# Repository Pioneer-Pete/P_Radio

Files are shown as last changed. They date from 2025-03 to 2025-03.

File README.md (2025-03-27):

## Introduciton

P_Radio was created as a homage to the iconic radios seen in the Portal video game series, to be distributed around UW-Platteville on April 1st, 2025.
The project's goal was to create an accurate representation of the Portal radios, both in appearance and sound, while retaining a sub-dollar cost per unit to enable a large number of units to be created and distributed.
Excluding the 3D printing costs, each unit meets the original goal, coming in at exactly $1. Filament costs ended up being approximately $0.40 per unit.

## Project Information

 3D Models: The base and shell were modeled in Fusion 360. STEP, STL, and F3D files are included.
 
 PCB Design: A custom PCB was designed using KiCAD, and four expansion ports were included for any future tinkerers out there.
 
 Code: The radio is powered by an STM8S003F3, a cost-effective 8-bit microcontroller. This necessitated using STM's STVD and STVP to program the boards. If remaking the project, I would look into using the STM Arduino library instead.

 Assembly: Everything snaps together without any hardware; the hole at the top of the shell accepts a ~4-inch length of standard 1.75mm filament to act as the "antenna". The batteries require a small strip of aluminum foil to complete the circuit at the end opposite the PCB. The calculated battery lifespan is 1-2 months, but it has yet to be tested.

## Fine Print

This is a non-commercial, personal project created for an April Fools' joke at the UW-Platteville campus. All copyrightable content (such as the Aperture Science logo) is the property of its respective owners and is used here for parody purposes only.

Feel free to use and modify the project as you like for fun, but please do not distribute any copyrighted content (logos, names) for commercial purposes.

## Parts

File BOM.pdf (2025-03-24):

Name | Part# | Cost/100 | Cost/150 | Cost/200 | Cost/300 | Cost/500
PCB | N/A | $ | 0.1834 | $ | 0.1623 | $ | 0.1591 | $ | 0.1559 | $ | 0.1521
MCU | STM8S003F3P6TR | $ 0.2305 | $ | 0.2004 | $ | 0.2004 | $ | 0.2004 | $ | 0.1735
VREG | MD3156E33QA3 | $ | 0.1005 | $ | 0.0871 | $ | 0.0871 | $ | 0.0871 | $ | 0.0770
Buzzer | SFN-1207PA6.5 | $ 0.0563 | $ 0.0563 | $ 0.0563 | $ | 0.0489 | $ | 0.0489
L | MGFL2012F2R2MT-LF | $ 0.0186 | $ 0.0186 | $ 0.0143 | $ | 0.0143 | $ | 0.0143
C1, C2 | CL10A105KO8NNNC | $ 0.0058 | $ 0.0058 | $ 0.0058 | $ | 0.0058 | $ | 0.0044
C5 | CL10A106MQ8NNNC | $ 0.0041 | $ 0.0041 | $ 0.0041 | $ | 0.0041 | $ | 0.0032
R1, R2 | TBD | $ 0.0020 | $ 0.0020 | $ 0.0020 | $ | 0.0020 | $ | 0.0020
AA Battery | N/A | $ 0.4028 | $ 0.4332 | $ 0.4483 | $ | 0.4635 | $ | 0.4756
3D Print | N/A | $ 0.4000 | $ 0.4000 | $ 0.4000 | $ | 0.4000 | $ | 0.4000
Per Unit | $ | 1.40 $ | 1.37 $ | 1.38 $ | 1.38 $ | 1.35
Total | $ | 140.40 $ | 205.47 $ | 275.48 $ | 414.60 $ | 675.50

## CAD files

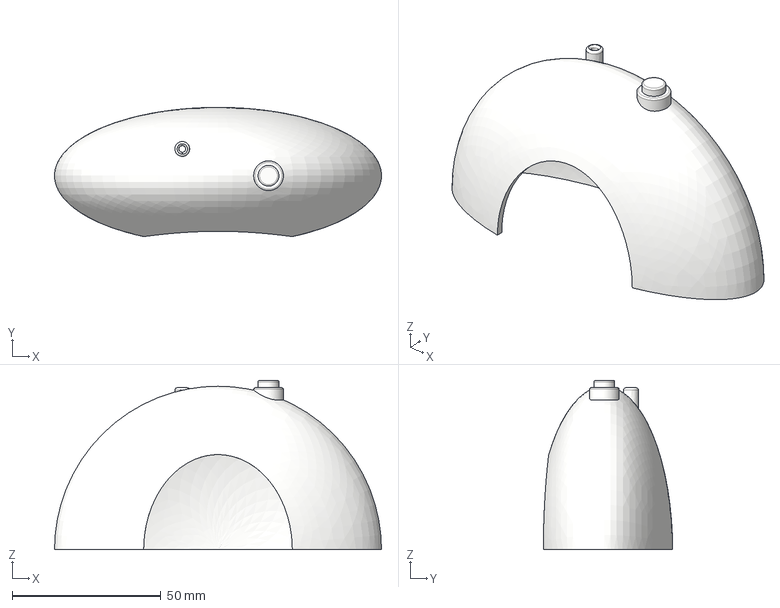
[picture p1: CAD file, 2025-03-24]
3D Models/Portal Radio Shell v8.step
110.0 x 43.5 x 57.0 mm

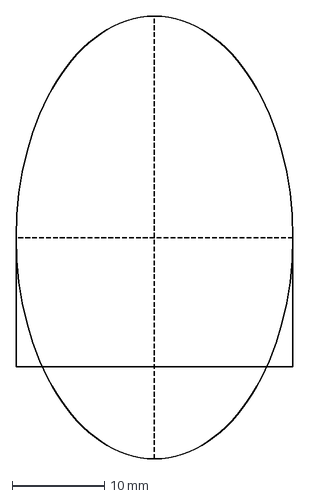
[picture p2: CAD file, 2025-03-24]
PCB/PCB Outine.dxf
30.0 x 48.0 mm

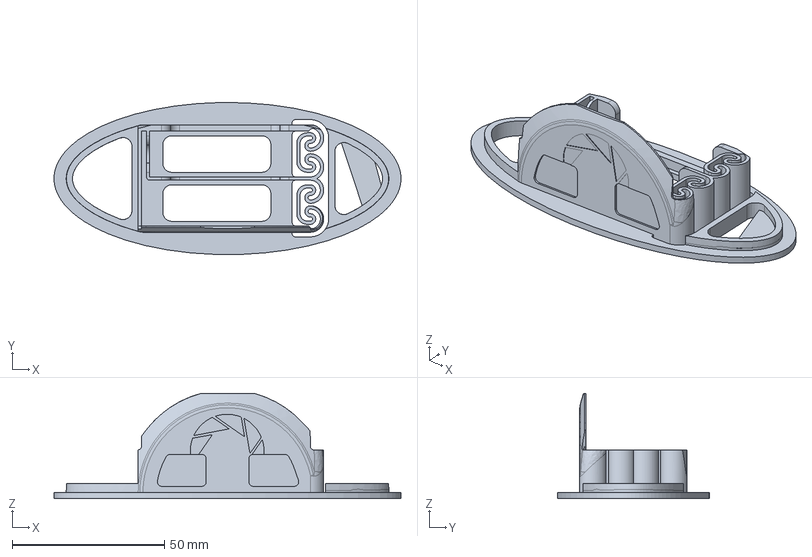
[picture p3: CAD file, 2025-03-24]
3D Models/Portal Radio Base v14.step
114.0 x 49.9 x 34.5 mm

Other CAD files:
3D Models/Portal Radio Base v14.f3d
3D Models/Portal Radio Shell v8.f3d

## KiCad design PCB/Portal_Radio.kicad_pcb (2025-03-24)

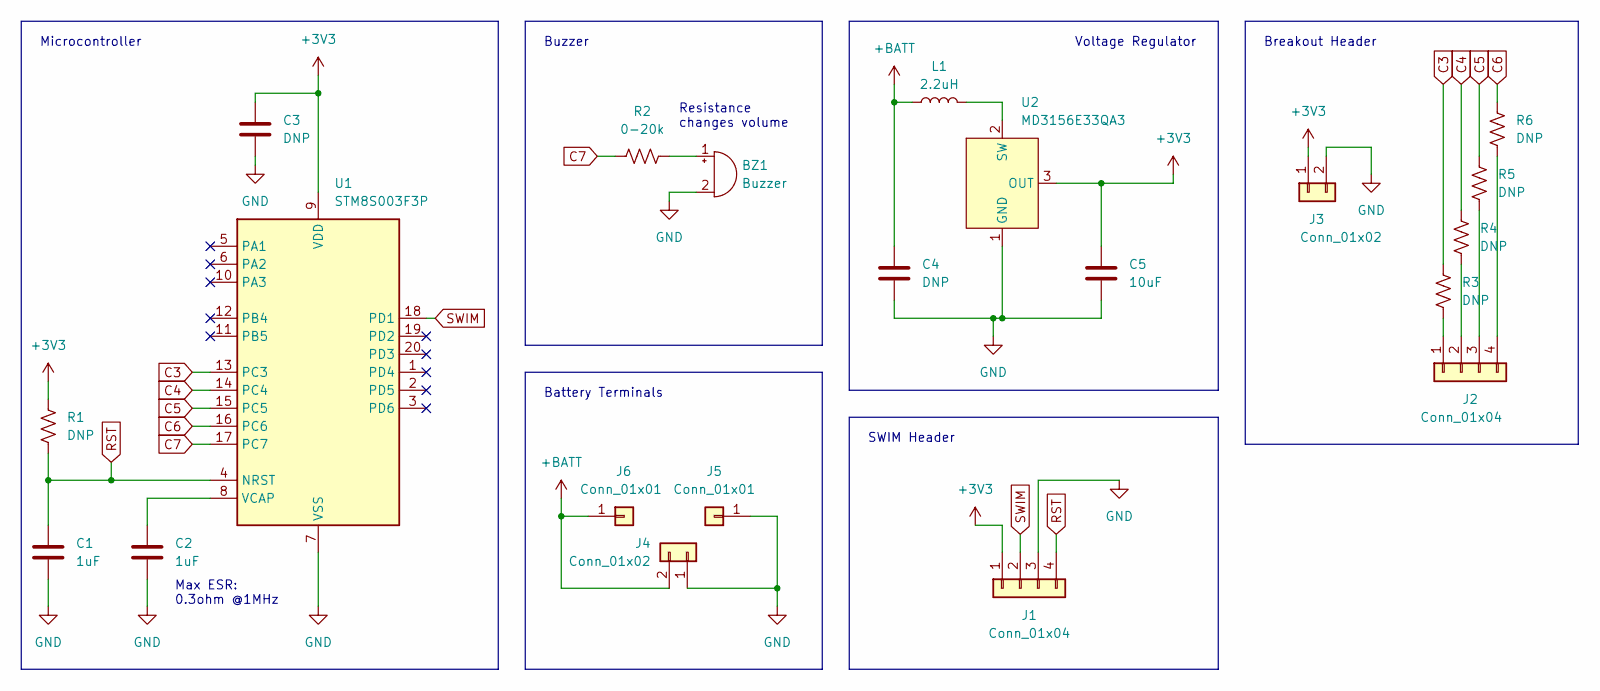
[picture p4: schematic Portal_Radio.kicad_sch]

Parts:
BZ1: Buzzer; MagneticBuzzer_ProSignal_ABT-410-RC
C1, C2: 1uF; C_0603_1608Metric
C3, C4: DNP; C_0603_1608Metric
C5: 10uF; C_0603_1608Metric
J1, J2: Conn_01x04; PinHeader_1x04_P2.54mm_Vertical
J3, J4: Conn_01x02; PinHeader_1x02_P2.54mm_Vertical
J5, J6: Conn_01x01; AA_Battery
L1: 2.2uH; L_0603_1608Metric
R1, R3, R4, R5, R6: DNP; R_0603_1608Metric
R2: 0-20k; R_0603_1608Metric
U1: STM8S003F3P; TSSOP-20_4.4x6.5mm_P0.65mm
U2: MD3156E33QA3; SOT-23-3

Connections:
+3V3: C3.1, C5.1, J1.1, J3.1, R1.1, U1.9 (VDD), U2.3 (OUT)
+BATT: C4.1, J4.2, J6.1, L1.1
C3: R3.1, U1.13 (PC3)
C4: R4.1, U1.14 (PC4)
C5: R5.1, U1.15 (PC5)
C6: R6.1, U1.16 (PC6)
C7: R2.1, U1.17 (PC7)
GND: BZ1.2 (-), C1.2, C2.2, C3.2, C4.2, C5.2, J1.3, J3.2, J4.1, J5.1, U1.7 (VSS), U2.1 (GND)
unnamed: BZ1.1 (+), R2.2
unnamed: J2.1, R3.2
unnamed: J2.2, R4.2
unnamed: J2.3, R5.2
unnamed: J2.4, R6.2
unnamed: C2.1, U1.8 (VCAP)
unnamed: L1.2, U2.2 (SW)
RST: C1.1, J1.4, R1.2, U1.4 (NRST)
SWIM: J1.2, U1.18 (PD1)

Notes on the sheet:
Resistance changes volume
Buzzer
Breakout Header
Voltage Regulator
Battery Terminals
Max ESR: 0.3ohm @1MHz
SWIM Header
Microcontroller

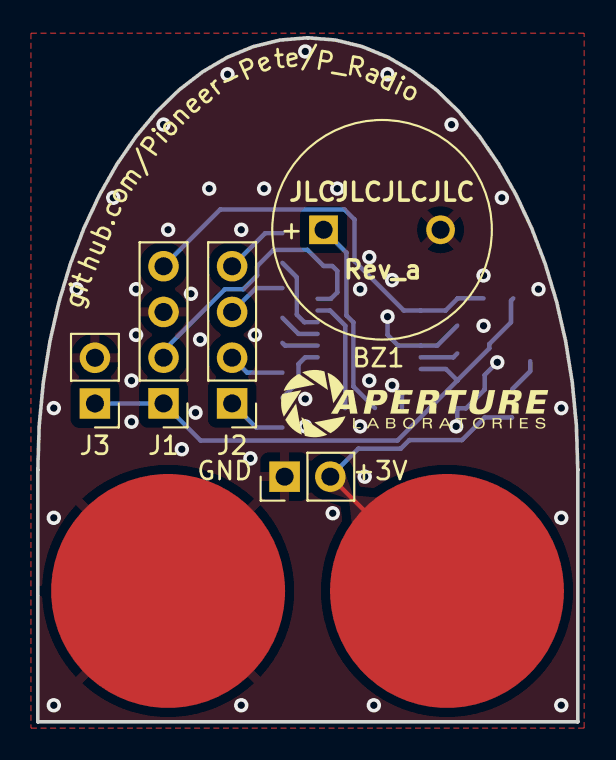
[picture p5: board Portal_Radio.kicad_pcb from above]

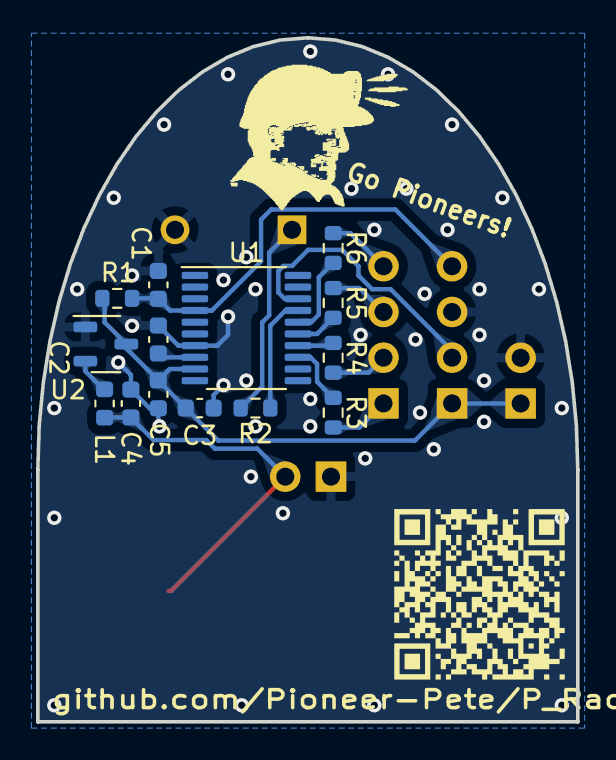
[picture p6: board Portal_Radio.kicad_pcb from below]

Board: 2 copper layers, 30.0 x 38.0 mm, 21 parts (14 on the bottom side), 17 nets.

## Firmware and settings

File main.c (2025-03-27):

#include "main.h"

#define EEPROM_STARTUP_DELAY_ADDR   ((uint32_t) FLASH_DATA_START_PHYSICAL_ADDRESS)

#define N_A6S  268  // A#6
#define N_A6   284  // A6
#define N_G6   318  // G6
#define N_F6S  337  // F#6
#define N_F6   357  // F6
#define N_E6   379  // E6
#define N_D6S  401  // D#6
#define N_D6   425  // D6
#define N_C6S  450  // C#6
#define N_C6   478  // C6
#define N_B5   506  // B5
#define N_A5S  536  // A#5
#define N_A5   568  // A5
#define N_G5S  601  // G#5
#define N_G5   637  // G5
#define N_F5S  675  // F#5
#define N_F5   716  // F5
#define N_E5   758  // E5
#define N_D5S  803  // D#5
#define N_D5   851  // D5
#define N_C5S  902  // C#5
#define N_C5   956  // C5
#define N_B4   1012 // B4
#define N_A4S  1072 // A#4
#define N_A4   1136 // A4
#define N_G4S  1204 // G#4
#define N_G4   1275 // G4
#define N_F4S  1351 // F#4
#define N_F4   1432 // F4
#define N_E4   1515 // E4
#define N_D4S  1607 // D#4
#define N_D4   1700 // D4
#define N_0    0    // Silence

// Note array 
const uint16_t notes[] = {
  N_D4,  N_D4,  N_0,   N_D4,  N_F4S, N_F4S, N_0,   N_F4S, N_G4,  N_0,   N_G4,  N_B4,  N_0,   N_B4,  N_A4,  N_0,   
  N_F4S, N_F4S, N_0,   N_F4S, N_G4,  N_G4,  N_0,   N_G4,  N_A4,  N_A4,  N_0,   N_B4,  N_G6,  N_F6S, N_A4,  N_E6,  
  N_D4,  N_D4,  N_F6S, N_D4,  N_F4S, N_F4S, N_D5,  N_F4S, N_G4,  N_0,   N_G4,  N_B4,  N_G6,  N_F6S, N_A4,  N_E6,  
  N_D4,  N_D4,  N_F6S, N_D4,  N_D6,  N_F4S, N_E6,  N_A5,  N_G4,  N_0,   N_G4,  N_B4,  N_0,   N_B4,  N_A4,  N_0,   
  N_E6,  N_D5,  N_F6S, N_G6,  N_G5,  N_E6,  N_E6,  N_0,   N_C6S, N_C5S, N_D6,  N_E6,  N_E5,  N_A5,  N_A4,  N_0,   
  N_A5,  N_A5,  N_A5,  N_D4,  N_F4S, N_F4S, N_D5,  N_F4S, N_G4,  N_0,   N_G4,  N_B4,  N_G6,  N_F6S, N_A4,  N_E6,  
  N_D4,  N_D4,  N_F6S, N_D4,  N_F4S, N_F4S, N_D5,  N_F4S, N_G4,  N_0,   N_G4,  N_B4,  N_G6,  N_F6S, N_A4,  N_E6,  
  N_D4,  N_D4,  N_F6S, N_D4,  N_D6,  N_F4S, N_E6,  N_A5,  N_G4,  N_0,   N_G4,  N_B4,  N_0,   N_B4,  N_A4,  N_0,   
  N_E6,  N_D5,  N_F6S, N_G6,  N_G5,  N_E6,  N_E6,  N_0,   N_C6S, N_C5S, N_D6,  N_E6,  N_E5,  N_A5,  N_A4,  N_0,   
  N_A5S, N_A5S, N_A4S, N_D6,  N_D6,  N_D5,  N_F6,  N_F6,  N_F6,  N_0,   N_A6,  N_A6S, N_A6,  N_F6,  N_D6,  N_0,   
  N_A5S, N_A5S, N_E5,  N_C6S, N_C6S, N_C5S, N_E6,  N_E6,  N_E6,  N_0,   N_G6,  N_A6,  N_G6,  N_E6,  N_C6S, N_0
};

volatile uint8_t current_note = 0;
volatile uint32_t startup_delay = 0;

/* Automatic wakeup unit interrupt */
INTERRUPT_HANDLER(AWU_IRQHandler, 1)
{
	if (AWU->CSR & AWU_CSR_AWUF);		// Reset flag by reading it
}

/* Timer 1 interrupt */
INTERRUPT_HANDLER(TIM1_UPD_OVF_TRG_BRK_IRQHandler, 11)
{
	GPIO_WriteReverse(GPIOC, GPIO_PIN_7);		// Toggle buzzer state
	TIM1->SR1 &= (uint8_t) ~TIM1_SR1_UIF;		// Clear interrupt flag
}

/* Timer 2 interrupt */
INTERRUPT_HANDLER(TIM2_UPD_OVF_BRK_IRQHandler, 13)
{
	if (notes[current_note] == 0) {
		TIM1_Cmd(DISABLE);  // Stop TIM1 if the note is 0
	} else {
		TIM1_SetAutoreload(notes[current_note]);
		TIM1_Cmd(ENABLE);   // Start TIM1
	}
	current_note = (uint8_t) ((current_note + 1) % 176);
	TIM2->SR1 &= (uint8_t) ~TIM2_SR1_UIF;		// Clear interrupt flag
}

int main(void)
{
	/* Initialize GPIO */
	GPIO_DeInit(GPIOC);
	GPIO_Init (GPIOC, GPIO_PIN_7, GPIO_MODE_OUT_PP_LOW_SLOW); // Declare PC7 as a default low push-pull output pin
	
	/* Initialize clocks & AWU */
	CLK_HSECmd(DISABLE);											// Disable HSE
	CLK_SYSCLKConfig(CLK_PRESCALER_HSIDIV8);	// HSI clock division 16MHz/8 = 2MHz
	CLK_SYSCLKConfig(CLK_PRESCALER_CPUDIV1);	// CPU clock division
	CLK_FastHaltWakeUpCmd(ENABLE);						// Set HSI as clock to use after HALT
	AWU_Init(AWU_TIMEBASE_30S);								// Initialize automatic wakeup unit to 30s
	
	/* Initialize timers */
	disableInterrupts();
	TIM1_TimeBaseInit(1, TIM1_COUNTERMODE_UP, notes[0], 0);
	TIM1_ITConfig(TIM1_IT_UPDATE, ENABLE);
	TIM1->CR1 |= TIM1_CR1_ARPE; // Enable shadow register for period
	TIM1_Cmd(ENABLE);
	TIM2_TimeBaseInit(TIM2_PRESCALER_16384, 15);
	TIM2_ITConfig(TIM2_IT_UPDATE, ENABLE);
	TIM2_Cmd(ENABLE);
	enableInterrupts();
	
	/* Verify system is running */
	while (current_note < 17) { // Play first few notes then disable timers
		__asm("WFI");
	}
	TIM1_Cmd(DISABLE);
	TIM2_Cmd(DISABLE);
	GPIO_DeInit(GPIOC);
	
	/* One-time startup delay */
	FLASH_Unlock(FLASH_MEMTYPE_DATA);																		// Unlock EEPROM
  startup_delay = *((volatile uint32_t*)EEPROM_STARTUP_DELAY_ADDR);		// Read startup_delay from EEPROM
	AWU_Cmd(ENABLE); 								// Enable automatic wakeup unit
	while (startup_delay < 1440) {	// 12*3600s/30s = 1440 30s AWU periods
	__asm("HALT"); 									// Enter low-power mode until automatic wakeup occurs
	startup_delay++;								// Increase period counter
	FLASH_ProgramWord(EEPROM_STARTUP_DELAY_ADDR, startup_delay);	// Write period counter to non-volitile memory
	}
	
	/* Disable stuff to save power */
	AWU_Cmd(DISABLE);																			// Disable automatic wakeup unit
	AWU_DeInit();																					// De-initialize automatic wakeup unit
	CLK_LSICmd(DISABLE);																	// Disable LSI
	CLK->PCKENR1 = CLK_PCKENR1_TIM1 | CLK_PCKENR1_TIM2;		// Enable only TIM1 and TIM2
	CLK->PCKENR2 = 0x00; 																	// Disable other peripherals
	
	/* Initialize GPIO again */
	GPIO_Init (GPIOC, GPIO_PIN_7, GPIO_MODE_OUT_PP_LOW_SLOW); // Declare PC7 as a default low push-pull output pin
	
	/* Initialize timers again */
	disableInterrupts();
	TIM1_TimeBaseInit(1, TIM1_COUNTERMODE_UP, notes[17], 0);
	TIM1_ITConfig(TIM1_IT_UPDATE, ENABLE);
	TIM1->CR1 |= TIM1_CR1_ARPE; // Enable shadow register for period
	TIM1_Cmd(ENABLE);
	TIM2_TimeBaseInit(TIM2_PRESCALER_16384, 15);
	TIM2_ITConfig(TIM2_IT_UPDATE, ENABLE);
	TIM2_Cmd(ENABLE);
	enableInterrupts();
	
	/* Begin playback */
	current_note = 17;
  while (1) {
		__asm("WFI"); // Enter low-power mode until an interrupt occurs
  }
}
